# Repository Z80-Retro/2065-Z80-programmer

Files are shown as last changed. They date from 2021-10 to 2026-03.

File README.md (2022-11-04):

An in-circuit programmer for the FLASH on a [2063-Z80](https://github.com/johnwinans/2063-Z80) board.

* A youtube playlist discussing this project and how to build your own can be found in [John's Basement](https://www.youtube.com/watch?v=oekucjDcNbA&list=PL3by7evD3F51Cf9QnsAEdgSQ4cz7HQZX5)
* A PDF version of the schematic can be found [here](2065-Z80-programmer.pdf).
* Here is the as-built [BOM](2065-Z80-programmer.md) with links to the datasheets for all the parts.
* Here is another [BOM](2065-Z80-programmer-sockets.md) with links to sockets for the chips.
* A Raspberry PI application for this board can be found in the [pi](pi) directory.
* To configure a new PI for use with this programmer board as well as to develop Z80 code 
for the Z80 Retro board, see this [PI Setup Guide](https://github.com/johnwinans/raspberry-pi-install)

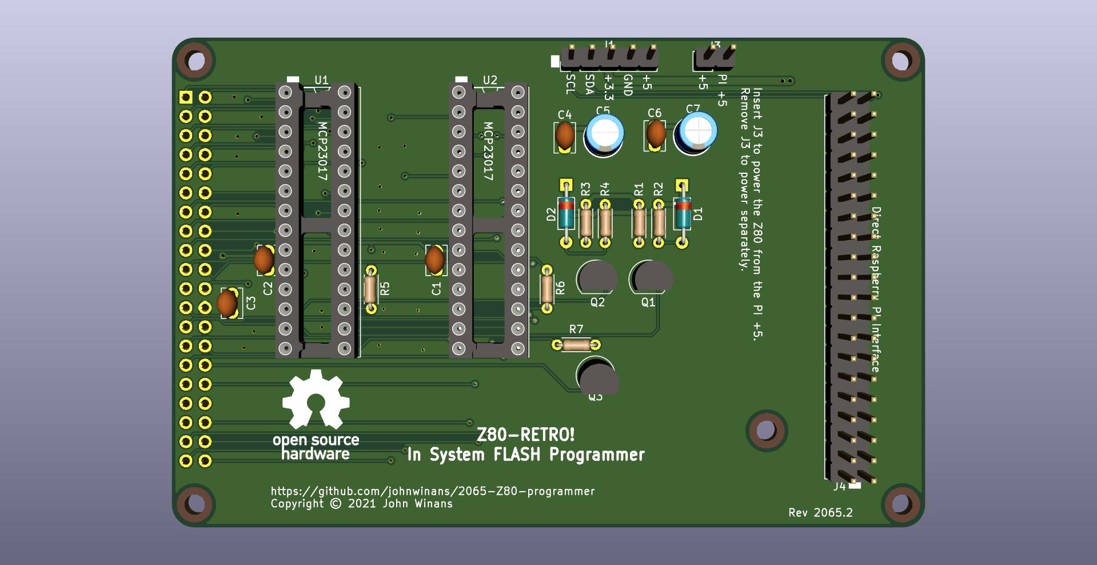
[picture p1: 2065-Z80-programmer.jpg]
PC Board Image ICE FLASH Programmer for 2063-Z80


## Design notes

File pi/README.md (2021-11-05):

# Software for a Raspberry PI and 2065-Z80-programmer

Copy these files onto a PI and type `make`

To verify that your FLASH programmer board is recognized by the Raspberry PI,
use the `i2cdetect` application like this:

```
pi@bot1:~/2065-Z80-programmer/pi$ i2cdetect -y 1
     0  1  2  3  4  5  6  7  8  9  a  b  c  d  e  f
00:          -- -- -- -- -- -- -- -- -- -- -- -- -- 
10: -- -- -- -- -- -- -- -- -- -- -- -- -- -- -- -- 
20: -- -- -- -- 24 -- 26 -- -- -- -- -- -- -- -- -- 
30: -- -- -- -- -- -- -- -- -- -- -- -- -- -- -- -- 
40: -- -- -- -- -- -- -- -- -- -- -- -- -- -- -- -- 
50: -- -- -- -- -- -- -- -- -- -- -- -- -- -- -- -- 
60: -- -- -- -- -- -- -- -- -- -- -- -- -- -- -- -- 
70: -- -- -- -- -- -- -- --                         
pi@bot1:~/2065-Z80-programmer/pi$ 
```

To program the FLASH, compile your code into a binary file
that begins at absolute address zero and run the flash app:

	flash < mycode.bin

If you cloned and built the test apps for the [2063-Z80](https://github.com/johnwinans/2063-Z80) Retro
project in your home directory then you can program and run blinky like this:

	./flash < ~/2063-Z80/tests/blinky1.bin

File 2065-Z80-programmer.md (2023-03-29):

# 2065-Z80-programmer.sch

## Tue Mar 28 20:51:58 2023

## Eeschema 5.1.5+dfsg1-2build2

## Component Count:31

Ref | Qty | Value | Digikey | Datasheet | Description
----|-----|-------|---------|-----------|------------
C1, C2, C3, C4, C6 | 5 | .1uF | 399-9859-1-ND‎ | https://api.kemet.com/component-edge/download/specsheet/C315C104M5U5TA7303.pdf | Unpolarized capacitor, small symbol
C5, C7 | 2 | 10uF | P975-ND | https://industrial.panasonic.com/cdbs/www-data/pdf/RDF0000/ABA0000C1059.pdf | Polarized capacitor, small US symbol
D1, D2 | 2 | 1N914 | 1N4148FSCT-ND | http://www.vishay.com/docs/85622/1n914.pdf | Diode
H1, H2, H3, H4, H5 | 5 | MountingHole |  |  | Mounting Hole without connection
J1 | 1 | Conn_01x05 | S1011EC-05-ND | https://media.digikey.com/PDF/Data%20Sheets/Sullins%20PDFs/xRxCzzzSxxN-RC_ST_11635-B.pdf | Generic connector, single row, 01x05, script generated (kicad-library-utils/schlib/autogen/connector/)
J2 | 1 | Conn_02x20_Counter_Clockwise | S6104-ND | https://media.digikey.com/pdf/Data%20Sheets/Sullins%20PDFs/Female_Headers.100_DS.pdf | Generic connector, double row, 02x20, counter clockwise pin numbering scheme (similar to DIP packge numbering), script generated (kicad-library-utils/schlib/autogen/connector/)
J3 | 1 | Conn_01x02 | S1011EC-02-ND | https://media.digikey.com/PDF/Data%20Sheets/Sullins%20PDFs/xRxCzzzSxxN-RC_ST_11635-B.pdf | Generic connector, single row, 01x02, script generated (kicad-library-utils/schlib/autogen/connector/)
J4 | 1 | Conn_02x20_Odd_Even | S2011EC-20-ND | https://drawings-pdf.s3.amazonaws.com/11636.pdf | Generic connector, double row, 02x20, odd/even pin numbering scheme (row 1 odd numbers, row 2 even numbers), script generated (kicad-library-utils/schlib/autogen/connector/)
LOGO10 | 1 | Logo_Open_Hardware_Small |  |  | Open Hardware logo, small
Q1, Q2 | 2 | 2N7000 | 2N7000TACT-ND | https://rocelec.widen.net/view/pdf/orqxwkxkq1/ONSM-S-A0003544006-1.pdf?t.download=true&u=5oefqw | 200V Vds, N-Channel MOSFET, 2.6V Logic Level, TO-92
Q3 | 1 | PN2222 | 1514-PN2222APBFREE-ND | https://my.centralsemi.com/datasheets/PN2221-2222A.PDF | NPN transistor, emitter/base/collector
R1, R2, R3, R4 | 4 | 2K7 | CF18JT2K70CT-ND | https://www.seielect.com/catalog/sei-cf_cfm.pdf | Resistor
R5, R6 | 2 | 10K | CF18JT10K0CT-ND | https://www.seielect.com/catalog/sei-cf_cfm.pdf | Resistor
R7 | 1 | 1K | CF18JT1K00CT-ND | https://www.seielect.com/catalog/sei-cf_cfm.pdf | Resistor
U1, U2 | 2 | MCP23017-E_SP | MCP23017-E/SP-ND | http://www.microchip.com/mymicrochip/filehandler.aspx?ddocname=en023709 | IC I/O EXPANDER I2C 16B 28SDIP

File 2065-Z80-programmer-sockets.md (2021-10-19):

## IC Sockets

You can buy fancy expensive ones, or you can buy cheap ones.
I used the cheap ones.  

Alternately, you can just solder the chips into the PCB.

As a tinkerer, the thing that is wrong with that is that it makes it very hard to 
recycle/repurpose the chips for something else in the future.  And with the 2021
chip-shortage in full-force on as I type this, being able to recycle chips is 
VERY appealing!

Be honest with yourself before sinking more money into sockets than the cost of the chips 
that go into them.  I expect the cheap ones to last for at least a decade or two.  Cheap
sockets in my hobby projects from 30 years ago are still doing fine.

Gold plating is better than tin.  Machined pins are better than
stamped spring-metal pins. 

I used four 14-pin sockets because I hand them in stock.  
But you can alternately order two 28-pin sockets if you prefer.

Ref | Qty | Value | Digikey | Datasheet | Description
----|-----|-------|---------|-----------|------------
U1,U2 | 4 | Socket | 2057-ICS-314-T-ND | https://app.adam-tech.com/products/download/data_sheet/199582/ics-3xx-t-data-sheet.pdf | DIP-14
U1,U2 | 2 | Socket | 2057-ICS-328-T-ND | https://app.adam-tech.com/products/download/data_sheet/199582/ics-3xx-t-data-sheet.pdf | DIP-28

## Shorting Blocks

This is used to (dis)connect the 5V power supply from the PI.

Ref | Qty | Value | Digikey | Datasheet | Description
----|-----|-------|---------|-----------|------------
J3 | 1 | Shorting Block | S9337-ND | https://s3.amazonaws.com/catalogspreads-pdf/PAGE128-129%20.100%20JUMPER.pdf | Shorting Jumper

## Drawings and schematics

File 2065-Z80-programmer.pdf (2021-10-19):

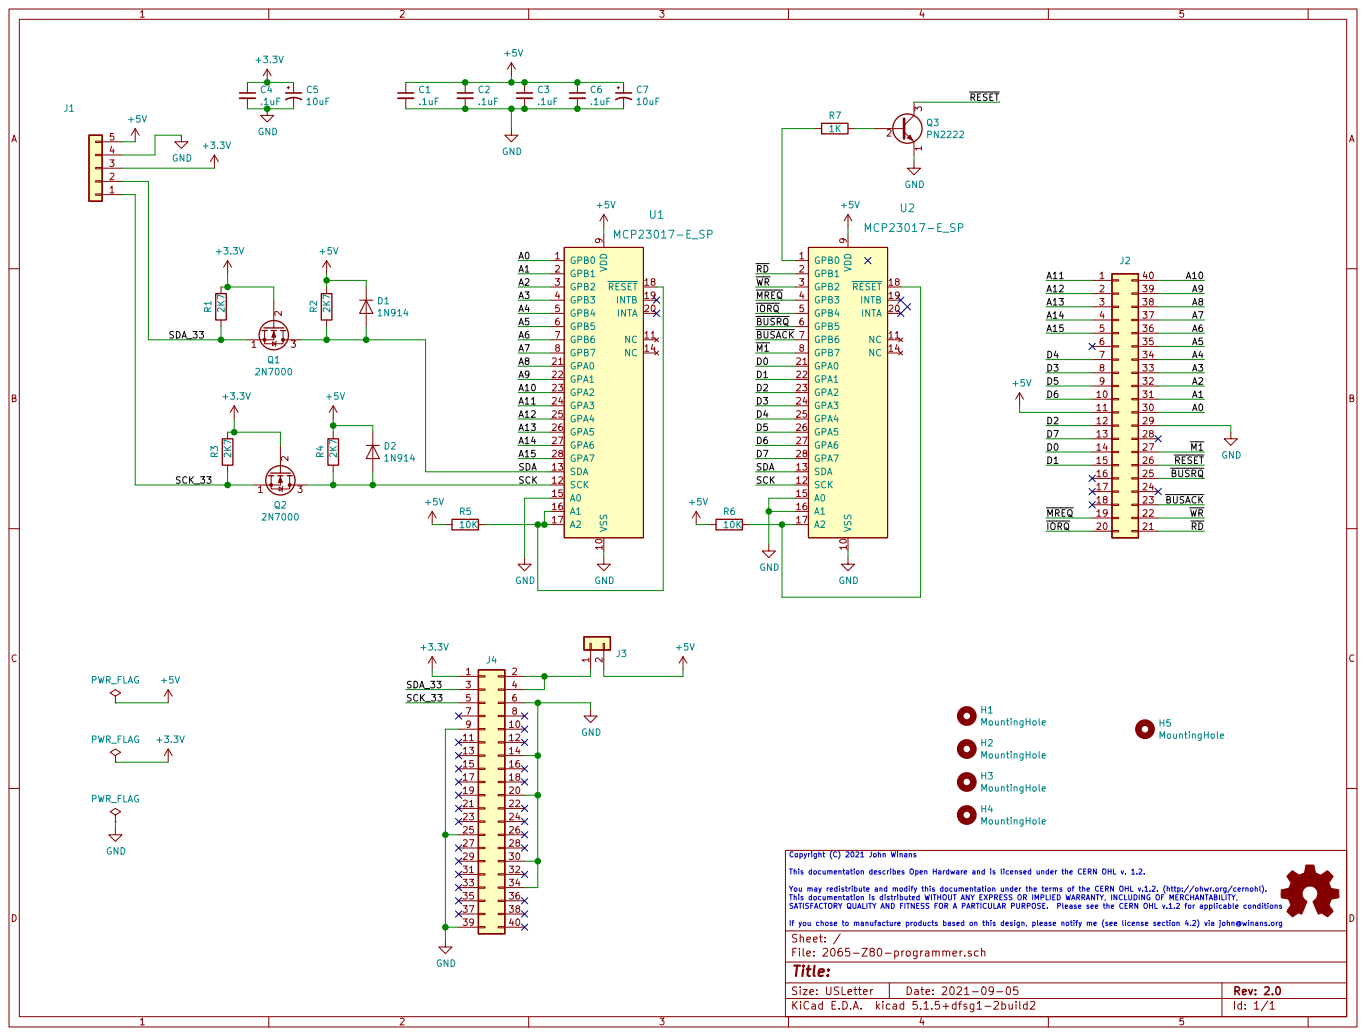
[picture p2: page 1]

File: 2065-Z80-programmer.sch Sheet: / 1

Copyright (C) 2021 John Winans This documentation describes Open Hardware and is licensed under the CERN OHL v. 1.2. You may redistribute and modify this documentation under the terms of the CERN OHL v.1.2. (http://ohwr.org/cernohl). This documentation is distributed WITHOUT ANY EXPRESS OR IMPLIED WARRANTY, INCLUDING OF MERCHANTABILITY, SATISFACTORY QUALITY AND FITNESS FOR A PARTICULAR PURPOSE. Please see the CERN OHL v.1.2 for applicable conditions

If you chose to manufacture products based on this design, please notify me (see license section 4.2) via john@winans.org

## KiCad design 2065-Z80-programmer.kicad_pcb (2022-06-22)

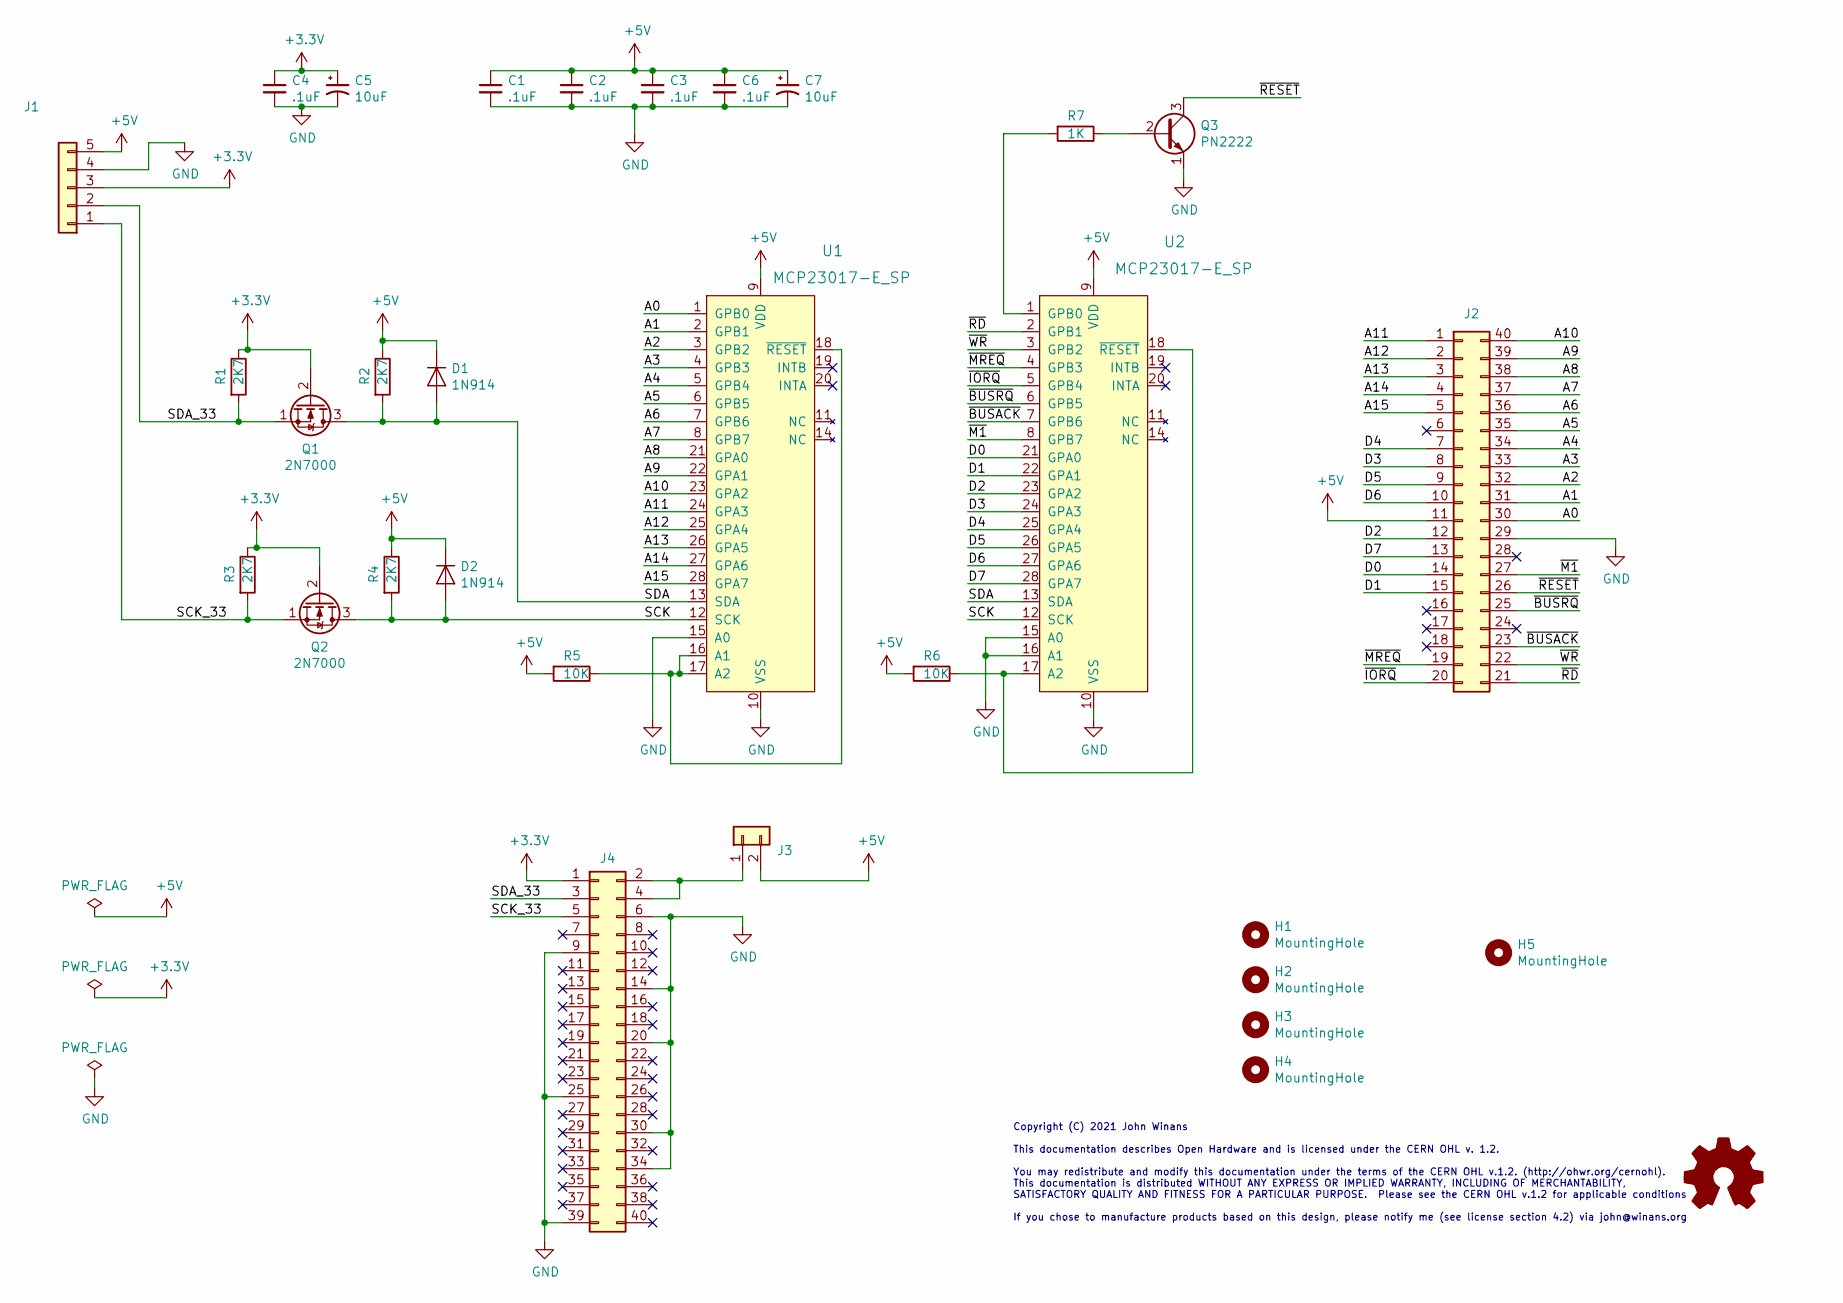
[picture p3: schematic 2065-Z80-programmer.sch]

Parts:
C1, C2, C3, C4, C6: .1uF; C_Disc_D3.8mm_W2.6mm_P2.50mm; Digi-Key_PN 399-9859-1-ND‎
C5, C7: 10uF; CP_Radial_D5.0mm_P2.50mm; MPN ECE-A1EKS100; Digi-Key_PN P975-ND
D1, D2: 1N914; D_DO-35_SOD27_P7.62mm_Horizontal; MPN 1N4148TR; Digi-Key_PN 1N4148FSCT-ND
H1, H2, H3, H4, H5: MountingHole; MountingHole_2.7mm_M2.5_DIN965
J1: Conn_01x05; PinHeader_1x05_P2.54mm_Vertical; Digi-Key_PN S1211EC-05-ND
J2: Conn_02x20_Counter_Clockwise; PinSocket_2x20_P2.54mm_Vertical_clockwise; MPN PPTC202LFBN-RC; Digi-Key_PN S6104-ND
J3: Conn_01x02; PinHeader_1x02_P2.54mm_Vertical; Digi-Key_PN S1011EC-02-ND
J4: Conn_02x20_Odd_Even; PinHeader_2x20_P2.54mm_Vertical; Digi-Key_PN S2011EC-20-ND
LOGO10: Logo_Open_Hardware_Small; OSHW-Logo_11.4x12mm_SilkScreen
Q1, Q2: 2N7000; TO-92; MPN 2N7000TA; Digi-Key_PN 2N7000TACT-ND
Q3: PN2222; TO-92L; Digi-Key_PN 1514-PN2222APBFREE-ND
R1, R2, R3, R4: 2K7; R_Axial_DIN0204_L3.6mm_D1.6mm_P5.08mm_Horizontal; MPN CF18JT2K70; Digi-Key_PN CF18JT2K70CT-ND
R5, R6: 10K; R_Axial_DIN0204_L3.6mm_D1.6mm_P5.08mm_Horizontal; MPN CF18JT10K0; Digi-Key_PN CF18JT10K0CT-ND
R7: 1K; R_Axial_DIN0204_L3.6mm_D1.6mm_P5.08mm_Horizontal; MPN CF18JT1K00; Digi-Key_PN CF18JT1K00CT-ND
U1, U2: MCP23017-E_SP; DIP-28_W7.62mm_Socket; MPN MCP23017-E/SP; Digi-Key_PN MCP23017-E/SP-ND

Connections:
+3V3: C4.1, C5.1, J1.3, J4.1, Q1.2 (G), Q2.2 (G), R1.1, R3.1
+5V: C1.1, C2.1, C3.1, C6.1, C7.1, D1.1 (K), D2.1 (K), J1.5, J2.11, J3.2, R2.1, R4.1, R5.2, R6.2, U1.9 (VDD), U2.9 (VDD)
/A0: J2.30, U1.1 (GPB0)
/A1: J2.31, U1.2 (GPB1)
/A2: J2.32, U1.3 (GPB2)
/A3: J2.33, U1.4 (GPB3)
/A4: J2.34, U1.5 (GPB4)
/A5: J2.35, U1.6 (GPB5)
/A6: J2.36, U1.7 (GPB6)
/A7: J2.37, U1.8 (GPB7)
/A8: J2.38, U1.21 (GPA0)
/A9: J2.39, U1.22 (GPA1)
/A10: J2.40, U1.23 (GPA2)
/A11: J2.1, U1.24 (GPA3)
/A12: J2.2, U1.25 (GPA4)
/A13: J2.3, U1.26 (GPA5)
/A14: J2.4, U1.27 (GPA6)
/A15: J2.5, U1.28 (GPA7)
/D0: J2.14, U2.21 (GPA0)
/D1: J2.15, U2.22 (GPA1)
/D2: J2.12, U2.23 (GPA2)
/D3: J2.8, U2.24 (GPA3)
/D4: J2.7, U2.25 (GPA4)
/D5: J2.9, U2.26 (GPA5)
/D6: J2.10, U2.27 (GPA6)
/D7: J2.13, U2.28 (GPA7)
/SCK: D2.2 (A), Q2.3 (D), R4.2, U1.12 (SCK), U2.12 (SCK)
/SCK_33: J1.1, J4.5, Q2.1 (S), R3.2
/SDA: D1.2 (A), Q1.3 (D), R2.2, U1.13 (SDA), U2.13 (SDA)
/SDA_33: J1.2, J4.3, Q1.1 (S), R1.2
/~BUSACK: J2.23, U2.7 (GPB6)
/~BUSRQ: J2.25, U2.6 (GPB5)
/~IORQ: J2.20, U2.5 (GPB4)
/~M1: J2.27, U2.8 (GPB7)
/~MREQ: J2.19, U2.4 (GPB3)
/~RD: J2.21, U2.2 (GPB1)
/~RESET: J2.26, Q3.3 (C)
/~WR: J2.22, U2.3 (GPB2)
GND: C1.2, C2.2, C3.2, C4.2, C5.2, C6.2, C7.2, J1.4, J2.29, J4.6, J4.9, J4.14, J4.20, J4.25, J4.30, J4.34, J4.39, Q3.1 (E), U1.10 (VSS), U1.15 (A0), U2.10 (VSS), U2.15 (A0), U2.16 (A1)
unnamed: J3.1, J4.2, J4.4
unnamed: Q3.2 (B), R7.1
unnamed: R5.1, U1.16 (A1), U1.17 (A2), U1.18 (~RESET)
unnamed: R6.1, U2.17 (A2), U2.18 (~RESET)
unnamed: R7.2, U2.1 (GPB0)

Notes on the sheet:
Copyright (C) 2021 John Winans This documentation describes Open Hardware and is licensed under the CERN OHL v. 1.2. You may redistribute and modify this documentation under the terms of the CERN OHL v.1.2. (http://ohwr.org/cernohl). This documentation is distributed WITHOUT ANY EXPRESS OR IMPLIED 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

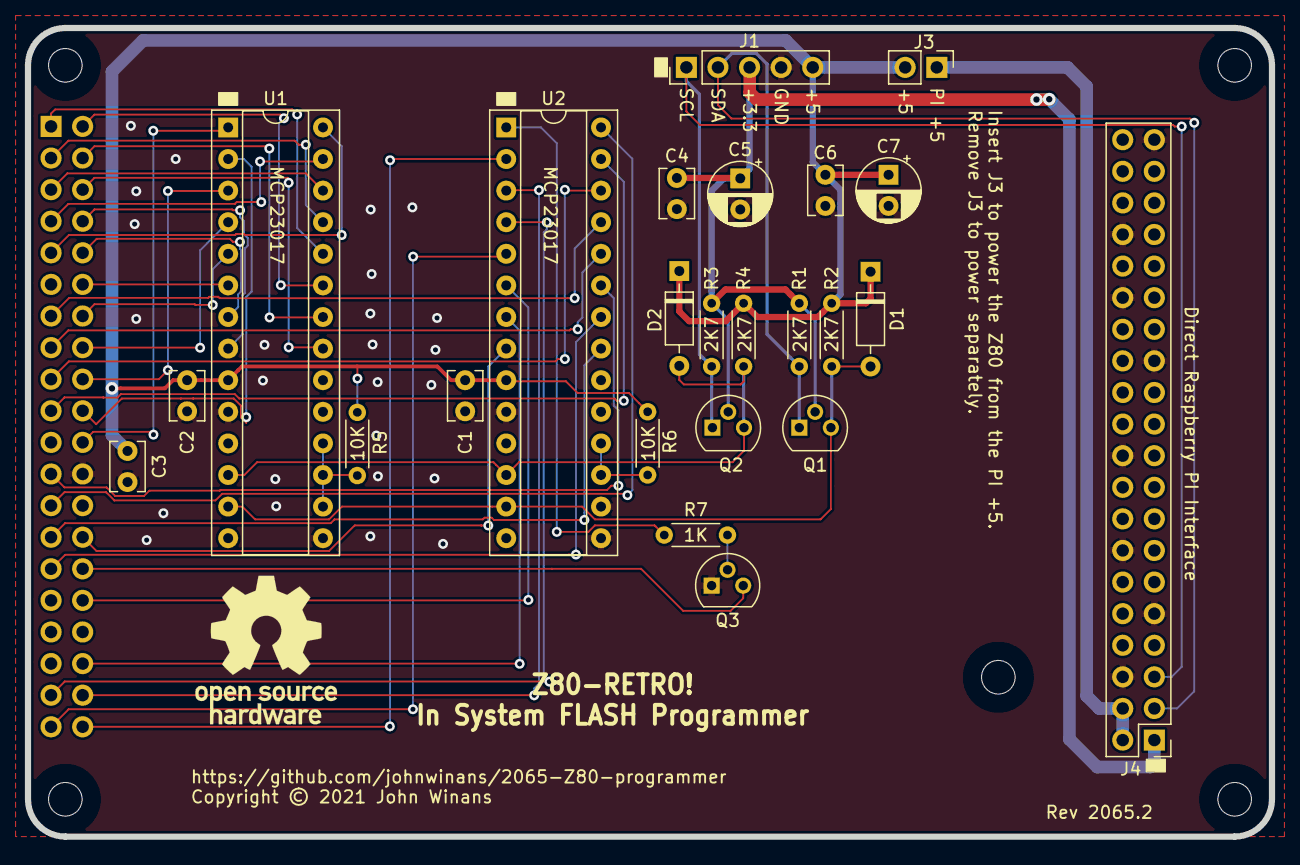
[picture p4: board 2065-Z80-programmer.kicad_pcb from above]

Board: 2 copper layers, 100.0 x 65.0 mm, 31 parts (1 on the bottom side), 44 nets.

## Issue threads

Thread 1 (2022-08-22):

Compilation bug with i2c version 4.2 gcc 10 on Linux mx 21

ewe2, 2022-08-22:
Here's the error, nothing serious, just a nuisance really.
```
$ make
cc -Wall -Werror    flash.c  -li2c -o flash
flash.c: In function ‘main’:
flash.c:535:50: error: format ‘%d’ expects argument of type ‘int’, but argument 2 has type ‘long unsigned int’ [-Werror=format=]
  535 |    printf("program file is too big, limiting to %d bytes\n", sizeof(buf));
      |                                                 ~^           ~~~~~~~~~~~
      |                                                  |           |
      |                                                  int         long unsigned int
      |                                                 %ld
cc1: all warnings being treated as errors
make: *** [<builtin>: flash] Error 1
```
I know most people are not Linux nerds and this will probably not apply to Windows users whose systems won't treat this as an error, but I thought it worth mentioning anyway, I can just fix it on my local copy with a preprocessor kludge or something.

johnwinans, 2022-08-22:
I suspect I have a 32-bit OS on my PI and you have a 64-bit version.
I'll cast it.

johnwinans, 2022-08-22:
Try fac3bd9deb04e0311b4795c2268ae3e6526cb988 and let me know if that works on your install.

ewe2, 2022-08-22:
Oh of course that makes sense. I was just testing compilation and didn't think about a Pi compilation. However I can also do this on my Potato whiich *does* run a 64bit OS and would have an issue here (although a Potato is massive overkill for the job  haha)..

Closed 2022-08-22.

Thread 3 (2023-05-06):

Change the retro-board header

johnwinans, 2023-05-06:
The FLASH programmer can not fit on top of the VDP board due to the heights of the components.  Without stackable pins, it can not go between the Retro board and VDP board.  As-is, it can not easily be used on a system with the VDP installed.

A solution is to change the header to the same type used on the VDP with long (stackable) pins and a tall connector housing to increase the standoff-height to clear the components on the VDP.

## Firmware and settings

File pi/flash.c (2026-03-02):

//****************************************************************************
//
//    2065-Z80-programmer I2C FLASH Programmer Application
//
//    Copyright (C) 2021 John Winans
//
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
//****************************************************************************

// Raspberry PI application to program the SST39SF010A FLASH
// chip on a 2063-Z80 board by way of using a 2065-Z80-programmer 
// adapter board.
//
// The PI communicates with the 2065-Z80-programmer using I2C.

// un-comment for the AM29F040B
//#define AM29F040B





#include <errno.h>

#include <unistd.h>
#include <stddef.h>
#include <stdio.h>
#include <stdlib.h>
#include <ctype.h>
#include <fcntl.h>
#include <sys/types.h>
#include <sys/uio.h>
#include <sys/ioctl.h>
#include <sys/file.h>
#include <sys/time.h>
#include <string.h>
#include <time.h>

#include <stdio.h>
#include <fcntl.h>
#include <unistd.h>
#include <stdlib.h>

#include <sys/ioctl.h>

#include <linux/i2c-dev.h>
#include <i2c/smbus.h>

#include <stdint.h>

#include "dbg.h"


#define I2C_DEV "/dev/i2c-1"

// MCP23017 (expand-o chip) I2C addresses
#define I2C_EX1		(0x26)	///< the one connected to the address bus
#define I2C_EX2		(0x24)	///< the one connected to the control and data bus


// I2C_EX1 A addr [0..7]
// I2C_EX1 B addr [8..15]
// I2C_EX2 A data [0..7]
// I2C_EX2 B bus control [RESET, /RD, /WR, /MREQ, /IORQ, /BUSRQ, /BUSACK, /M1]

// control bus pin assignment on EX2 port B
#define	IO_RESET	(0x01)	///< ALWAYS output
#define	IO_RD		(0x02)	///< output when take over the bus, else input/float
#define	IO_WR		(0x04)	///< output when take over the bus, else input/float
#define	IO_MREQ		(0x08)	///< output when take over the bus, else input/float
#define	IO_IORQ		(0x10)	///< output when take over the bus, else input/float
#define	IO_BUSRQ	(0x20)	///< ALWAYS output
#define	IO_BUSACK	(0x40)	///< ALWAYS input
#define	IO_M1		(0x80)	///< ALWAYS input

// These are used to configure the control ports when transitioning from 
// passive to active control mode (ie, when the Z80 bus is taken over by the
// programmer.  Direction control = 1 for inputs, 0 for outputs.
#define IO_DIR_BUS_CTL_ON	(IO_BUSACK|IO_M1)		// all out (0) except /BUSACK & /M1
#define IO_DIR_BUS_CTL_OFF	(~(IO_RESET|IO_BUSRQ))	// /BUSRQ & RESET = out, all others=in


// These are used to set the direction of all 8 bits of a port to in or out
// mode when configuring the address and data lines.
#define IO_DIR_BUS_AD_IN	(0xff)	// all bits = 1 = input
#define IO_DIR_BUS_AD_OUT	(0)		// all bits = 0 = output


/**
* This is used to make the logic that has to toggle one bit (without
* knowing the state of the others) easier to implement.
* It is initialized to the power-on-reset value of the MCP23017 chip.
*****************************************************************************/
static uint8_t ctl_cache = 0xff;		// a copy of the last-written control latch value

/**
* This is a copy of the last-written data-direction seting.
* We use it to figure out if it needs to be changed or not when
* we need to put it into a given direction.
* It is initialized into an impossible value so that the 'first time'
* it is checked, it will indicate that it needs to be set.
*****************************************************************************/
static uint8_t data_dir_cache = 0x0f;


/**
* Open the I2C port.
* @param dev The device file to open (on a PI, use /dev/i2c-1)
* @return The file-descriptor or -1 if the open failed.
*****************************************************************************/
static int openIIC(
    const char *dev
    )
{
    // Create a file descriptor for the I2C bus
    int fd = open(dev, O_RDWR);
    if (fd<0)
        DBG("open failed. dev='%s'\n", dev);

    return fd;
}


/**
* Write the given values to ports A and B of the addr-specified MCP23017.
* @param iic The iic file handle
* @param addr The iic address of the MCP23017 device to write data into
* @param a The value to write to the GPIO A port register
* @param b The value to write to the GPIO B port register
*****************************************************************************/
int mcp23017_write(int iic, int addr, uint8_t a, uint8_t b)
{
    int rc = 0;
    rc = ioctl(iic, I2C_SLAVE, addr);
    if (rc < 0)
	{
        DBG("ioctl(I2C_SLAVE, %d) failed.  rc=%d\n", addr, rc);
		return -1;
	}

    uint8_t txbuf[5];
    txbuf[0] = 0x12;				// register 0x12 = GPIOA
    txbuf[1] = a;					// GPIOA value
    txbuf[2] = b;					// GPIOB value
    if ((rc=write(iic, txbuf, 3)) != 3)
	{
        DBG("write() failed %d\n", rc);
		return -1;
	}
	return 0;
}

/**
* Write the given value to port A of the addr-specified MCP23017.
* @param iic The iic file handle
* @param addr The iic address of the MCP23017 device to write data into
* @param a The value to write to the GPIO A port register
*****************************************************************************/
int mcp23017_write_a(int iic, int addr, uint8_t a)
{
    int rc = 0;
    rc = ioctl(iic, I2C_SLAVE, addr);
    if (rc < 0)
	{
        DBG("ioctl(I2C_SLAVE, %d) failed.  rc=%d\n", addr, rc);
		return -1;
	}

    uint8_t txbuf[5];
    txbuf[0] = 0x12;				// register 0x12 = GPIOA
    txbuf[1] = a;					// GPIOA value
    if ((rc=write(iic, txbuf, 2)) != 2)
	{
        DBG("write() failed %d\n", rc);
		return -1;
	}
	return 0;
}
/**
* Write the given value to port B of the addr-specified MCP23017.
* @param iic The iic file handle
* @param addr The iic address of the MCP23017 device to write data into
* @param b The value to write to the GPIO B port register
*****************************************************************************/
int mcp23017_write_b(int iic, int addr, uint8_t b)
{
    int rc = 0;
    rc = ioctl(iic, I2C_SLAVE, addr);
    if (rc < 0)
	{
        DBG("ioctl(I2C_SLAVE, %d) failed.  rc=%d\n", addr, rc);
		return -1;
	}

    uint8_t txbuf[5];
    txbuf[0] = 0x13;				// register 0x13 = GPIOB
    txbuf[1] = b;					// GPIOB value
    if ((rc=write(iic, txbuf, 2)) != 2)
	{
        DBG("write() failed %d\n", rc);
		return -1;
	}
	return 0;
}


/**
* Return 16-bit value from ports B and A (B=msb & A=lsb)
* @param iic The iic file handle
* @param addr The iic address of the MCP23017 device to write data into
* @return a 16-bit value comprised of the value read from port A (in the lsb)
*	and the value of port B (in the MSB).
*****************************************************************************/
uint16_t mcp23017_read(int iic, int addr)
{
    int rc = 0;
    rc = ioctl(iic, I2C_SLAVE, addr);
    if (rc < 0)
	{
        DBG("ioctl(I2C_SLAVE, %d) failed.  rc=%d\n", addr, rc);
		return -1;
	}

    uint8_t xbuf[5];
    xbuf[0] = 0x12;				// register 0x12 = GPIOA
    if ((rc=write(iic, xbuf, 1)) != 1)
	{
        DBG("write() failed %d\n", rc);
		return -1;
	}

	if ((rc=read(iic, xbuf, 2)) != 2)
	{
        DBG("read() failed %d\n", rc);
		return -1;
	}

	return xbuf[0]|(xbuf[1]<<8);	// A=lsb
}

/**
* Set the direction control of each of the pins of ports A and B of the
* MCP23017 at the given address.
* @param iic The iic file handle
* @param addr The iic address of the MCP23017 device to set the bit-directions
* @param a An 8-bit value indicating which pins are to be configured for
* output (0) and which for input (1). 
*****************************************************************************/
int mcp23017_set_dir(int iic, uint8_t addr, uint8_t a, uint8_t b)
{
    int rc = 0;
    rc = ioctl(iic, I2C_SLAVE, addr);
    if (rc < 0)
	{
        DBG("ioctl(I2C_SLAVE, %d) failed.  rc=%d\n", (int)addr, rc);
		return -1;
	}

    uint8_t txbuf[5];
    txbuf[0] = 0;					// register 0 = DIRA
    txbuf[1] = a;					// DIRA value
    txbuf[2] = b;					// DIRB value
    if ((rc=write(iic, txbuf, 3)) != 3)
	{
        DBG("write() failed %d\n", rc);
		return -1;
	}
	return 0;
}

/**
* Set up the MCP23017 with all CTL line directions set to input (floating) 
* except for RESET & /BUSRQ.
* @param iic The iic file handle
* @note This will leave the /BUSRQ signal asserted (and RESET not asserted.)
*****************************************************************************/
void mcp23017_init(int fd) 
{
	// preset the addres bus to zero (it doesn't really matter)
	mcp23017_write(fd, I2C_EX1, 0, 0);

	// preset all the control lines to un-asserted except /BUSRQ
	ctl_cache = (~IO_BUSRQ)&(~IO_RESET);
	mcp23017_write(fd, I2C_EX2, 0xff, ctl_cache);	// data value = don't care

	// put EX2.A (databus) into input and EX2.B (control) as appropriate
	data_dir_cache = IO_DIR_BUS_AD_IN;
	mcp23017_set_dir(fd, I2C_EX2, data_dir_cache, IO_DIR_BUS_CTL_OFF);	// this will assert /BUSRQ 

	// Cycle the RESET signal here to make sure the FLASH select logic is reset
	mcp23017_write_b(fd, I2C_EX2, ctl_cache|IO_RESET);
	mcp23017_write_b(fd, I2C_EX2, ctl_cache);	

	// Note that the Z80 is likely to glitch the /BUSACK here due
	// to it getting reset, but that is OK.

	// At this point, the Z80 will have yielded control of the bus... 
	// so take over the rest of the control signals.
	// We don't care about /BUSACK because we want this to work even if
	// there is no Z80 on the motherboard.
	mcp23017_set_dir(fd, I2C_EX2, data_dir_cache, IO_DIR_BUS_CTL_ON);	

	// put all bits of EX1 (address bus) into output mode
	mcp23017_set_dir(fd, I2C_EX1, IO_DIR_BUS_AD_OUT, IO_DIR_BUS_AD_OUT);	

}

/**
* De-assert /BUSRQ and cycle the RESET signal.
* @param iic The iic file handle
*****************************************************************************/
void bus_release(int iic)
{
	// Float all the address, data, and control lines EXCEPT for RESET & /BUSRQ
	mcp23017_set_dir(iic, I2C_EX1, IO_DIR_BUS_AD_IN, IO_DIR_BUS_AD_IN);		// release the address lines
	mcp23017_set_dir(iic, I2C_EX2, IO_DIR_BUS_AD_IN, IO_DIR_BUS_CTL_OFF);	// release most of the ctl signals

	// /BUSRQ will have already be asserted 
	ctl_cache = IO_RESET|IO_BUSRQ; 		// de-assert /BUSRQ and assert RESET
	mcp23017_write_b(iic, I2C_EX2, ctl_cache);	

	// de-assert the RESET (while keeping /BUSRQ signal de-asserted)
	ctl_cache &= ~IO_RESET;				// RESET=0, leave IO_BUSRQ=1
	mcp23017_write_b(iic, I2C_EX2, ctl_cache);
}

/**
* Program a byte in the FLASH
*
* @param iic The iic file handle
* @param addr The address of the byte to be programmed
* @param data The byte value to write into the FLASH
* @note It is assumed that mcp23017_init() is called before this.
*****************************************************************************/
int bus_write_cycle(int iic, uint16_t addr, uint8_t data)
{
	// set the value on the address bus
	mcp23017_write(iic, I2C_EX1, (addr>>8)&0xff, addr&0xff);

	// stage the data to write 
	mcp23017_write_a(iic, I2C_EX2, data);

	if (data_dir_cache!=IO_DIR_BUS_AD_OUT)
	{
		// turn on the data drivers
		data_dir_cache=IO_DIR_BUS_AD_OUT;
		mcp23017_set_dir(iic, I2C_EX2, data_dir_cache, IO_DIR_BUS_CTL_ON);
	}

	// assert /MREQ & /WR
	mcp23017_write_b(iic, I2C_EX2, ctl_cache&(~IO_MREQ)&(~IO_WR));

	// un-assert /MREQ & /WR
	mcp23017_write_b(iic, I2C_EX2, ctl_cache);

	return 0;
}

/**
* Read a byte from flash at address: addr.
* @param iic The iic file handle
* @param addr The address of the byte to be read
* @return The byte value read from the FLASH
* @note It is assumed that mcp23017_init() is called before this.
*****************************************************************************/
uint8_t bus_read_cycle(int iic, uint16_t addr)
{
	// set the value on the address bus
	mcp23017_write(iic, I2C_EX1, (addr>>8)&0xff, addr&0xff);

	if (data_dir_cache!=IO_DIR_BUS_AD_IN)
	{
		// turn off the data drivers
		data_dir_cache=IO_DIR_BUS_AD_IN;
		mcp23017_set_dir(iic, I2C_EX2, data_dir_cache, IO_DIR_BUS_CTL_ON);
	}

	// assert /MREQ & /RD
	mcp23017_write_b(iic, I2C_EX2, ctl_cache&(~IO_MREQ)&(~IO_RD));

	// READ the data bus
	int rc = mcp23017_read(iic, I2C_EX2);

	// un-assert /MREQ & /RD
	mcp23017_write_b(iic, I2C_EX2, ctl_cache);

	return rc&0xff;
}



//***************************************************************************
//***************************************************************************
//***************************************************************************
//***************************************************************************




/**
* Send the security sequence to the FLASH
* @param iic The iic file handle
* @param cmd The value of the command byte to send to the FLASH
*****************************************************************************/
int flash_send_sdp(int iic, uint8_t cmd)
{
	int rc = 0;
#ifdef AM29F040B
	rc |= bus_write_cycle(iic, 0x555, 0xAA);
	rc |= bus_write_cycle(iic, 0x2AA, 0x55);
	rc |= bus_write_cycle(iic, 0x555, cmd);
#else
	rc |= bus_write_cycle(iic, 0x5555, 0xAA);
	rc |= bus_write_cycle(iic, 0x2AAA, 0x55);
	rc |= bus_write_cycle(iic, 0x5555, cmd);
#endif

	return rc;
}

/**
* Read and print the FLASH Product ID.
* @param iic The iic file handle
* @return The manufacturer (in the MSB) and the product (in the LSB) 
*	of the FLASH
*****************************************************************************/
uint16_t flash_read_product_id(int iic)
{
	flash_send_sdp(iic, 0x90);				// Software ID read

	uint16_t mfg = bus_read_cycle(iic, 0);	// read a byte from address 0
#ifdef AM29F040B
	flash_send_sdp(iic, 0x90);				// Software ID read
#endif
	uint16_t prod = bus_read_cycle(iic, 1);	// read a byte from address 1
	printf("Product ID: 0x%02x, 0x%02x\n", mfg, prod);

#ifndef AM29F040B
	flash_send_sdp(iic, 0xf0);				// Software ID Exit
#endif

	return (mfg<<8)|prod;
}

/**
* Erase the entire FLASH chip.
* @param iic The iic file handle
* @note This operation can take up to 100msec.
*****************************************************************************/
int flash_chip_erase(int iic)
{
	flash_send_sdp(iic, 0x80);
	flash_send_sdp(iic, 0x10);
	usleep(200000);		// some extra margin!
	return 0;
}

/**
* Program one single byte data into address addr.
* @param iic The iic file handle
* @param addr The address of the byte to be programmed
* @param data The byte value to write into the FLASH
* @note This operation can take up to 20usec.
*****************************************************************************/
int flash_program_byte(int iic, uint16_t addr, uint8_t data)
{
#if 1
	if (data == 0xff)
		return 0;		// no need to program 0xff since that is the erased state
#endif

	flash_send_sdp(iic, 0xa0);
	bus_write_cycle(iic, addr, data);
	usleep(21);		// some extra margin!
	return 0;
}



/**
* Modus operandi:
*
* Open the I2C port.
* Initialize the MCP23017s and assert /BUSRQ to steal the Z80 BUS.
* Read and print the FLASH product ID.
* If the ID is invalid, exit with an error.
* Bulk-erase the entire FLASH chip.
* Read and program one byte at-a-time from a binary STDIN stream.
*	The first byte will be written into address 0, the second to address 1,...
* When hit EOF read the entire contents of the FLASH back in, compare it 
*	to the original data, and print a success/fail message.
* Release the Z80 bus.
*****************************************************************************/
int main()
{
    int     iic;
	char	buf[65536];

    iic = openIIC(I2C_DEV);
	mcp23017_init(iic);

	uint16_t d = flash_read_product_id(iic);
#ifdef AM29F040B
	if (d != 0x01a4)
#else
	if (d != 0xbfb5 && d != 0xbfb6 && d != 0xbfb7 && d != 0x3ec0)
#endif
	{
		printf("Invalid FLASH signature: 0x%04x != 0xbfb5\n", d);
		exit(1);
	}

#if 0
bus_release(iic);
exit(0);
#endif

	uint32_t addr = 0;
#if 1

#if 1
	printf("Erasing entire chip\n");
	flash_chip_erase(iic);
#endif

#if 1

	printf("Programming\n");
	// Program the flash direct from stdin 
	uint8_t b;
	while(read(fileno(stdin), &b, 1) == 1)
	{
		if (addr%16 == 0)
			printf("%s%04x:", addr==0?"":"\n", addr);
		printf(" %02x", b);

		buf[addr] = b;
		flash_program_byte(iic, addr, b);
		++addr;

		if (addr >= sizeof(buf))
		{
			printf("program file is too big, limiting to %d bytes\n", (int)sizeof(buf));
			break;
		}
	}
	printf("\n");

	printf("**********************************************************\n");
#endif

#endif

	printf("Reading\n");
	char	rbuf[65536];

	// read the flash back again
	if (addr == 0)
		addr = 0x100;	// just read 0x100 bytes if we didn't write anything

	uint32_t raddr = 0;
	while(raddr < addr)
	{
		rbuf[raddr] = bus_read_cycle(iic, raddr);

		if (raddr%16 == 0)
			printf("%s%04x:", raddr==0?"":"\n", raddr);
		printf(" %02x", rbuf[raddr]);

		++raddr;
	}
	printf("\n");

	bus_release(iic);

	
	printf("Verifying.\n");
	if (memcmp(buf, rbuf, addr) == 0)
		printf("SUCCESS!\n");
	else
		printf("FAILED!\n");

	return 0;
}

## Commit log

2021-09-13 Initial import
    [2065-Z80-programmer-B_Cu.gbl, 2065-Z80-programmer-B_Mask.gbs, 2065-Z80-programmer-B_Paste.gbp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]
2021-10-19 Pull up /RESET
    [2065-Z80-programmer.kicad_pcb, 2065-Z80-programmer.sch]
2021-10-19 Add 5V clamping diodes to I2C lines Move mounting hole clear of user-1 header
    [2065-Z80-programmer-B_Cu.gbl, 2065-Z80-programmer-B_Mask.gbs, 2065-Z80-programmer-B_Paste.gbp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]
2021-10-19 Update PCB image.
2021-10-19 Add links to YouTube series, BOM, & schematic
2021-10-19 Update sch, pcb, & BOM to match as-built v1.0.
    [2065-Z80-programmer.sch]
2021-10-19 Correct J2 to female connector.
    [2065-Z80-programmer.sch]
2021-10-21 Cosmetic silkscreen cleanup
    [2065-Z80-programmer-B_Cu.gbl, 2065-Z80-programmer-B_Mask.gbs, 2065-Z80-programmer-B_Paste.gbp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]
2021-10-22 Change Z80 header to socket so looks right in 3D
    [2065-Z80-programmer-B_Cu.gbl, 2065-Z80-programmer-B_Mask.gbs, 2065-Z80-programmer-B_Paste.gbp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]
2021-10-22 Render new 3D image with right connectors
2021-10-22 Remove disembodied NC markers.
    [2065-Z80-programmer.sch]
2021-10-27 doc, speed improvements, proper RESET handling
    [flash.c]
2021-10-29 Add note about using i2cdetect
2021-10-30 Don't need sudo with i2cdetect
2021-11-05 Cleanup doc & RESET control
    [flash.c]
2021-11-10 Add optimization to skip programming 0xff
    [flash.c]
2022-06-22 Add 1K value to silkscreen for R7
    [2065-Z80-programmer.kicad_pcb]
2022-06-22 Move H5 1mm to the left & ignore scratch files.
    [2065-Z80-programmer-B_Cu.gbl, 2065-Z80-programmer-B_Mask.gbs, 2065-Z80-programmer-B_Paste.gbp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]
2022-06-24 Remove stale driver gerber map files.
    [2065-Z80-programmer-NPTH-drl_map.gbr, 2065-Z80-programmer-PTH-drl_map.gbr]
2022-08-22 Cast some printf() args for signedness and size
2023-03-29 Change Digikey part numbers on 1x5 header
    [2065-Z80-programmer.sch]

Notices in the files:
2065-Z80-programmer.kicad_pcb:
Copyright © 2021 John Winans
